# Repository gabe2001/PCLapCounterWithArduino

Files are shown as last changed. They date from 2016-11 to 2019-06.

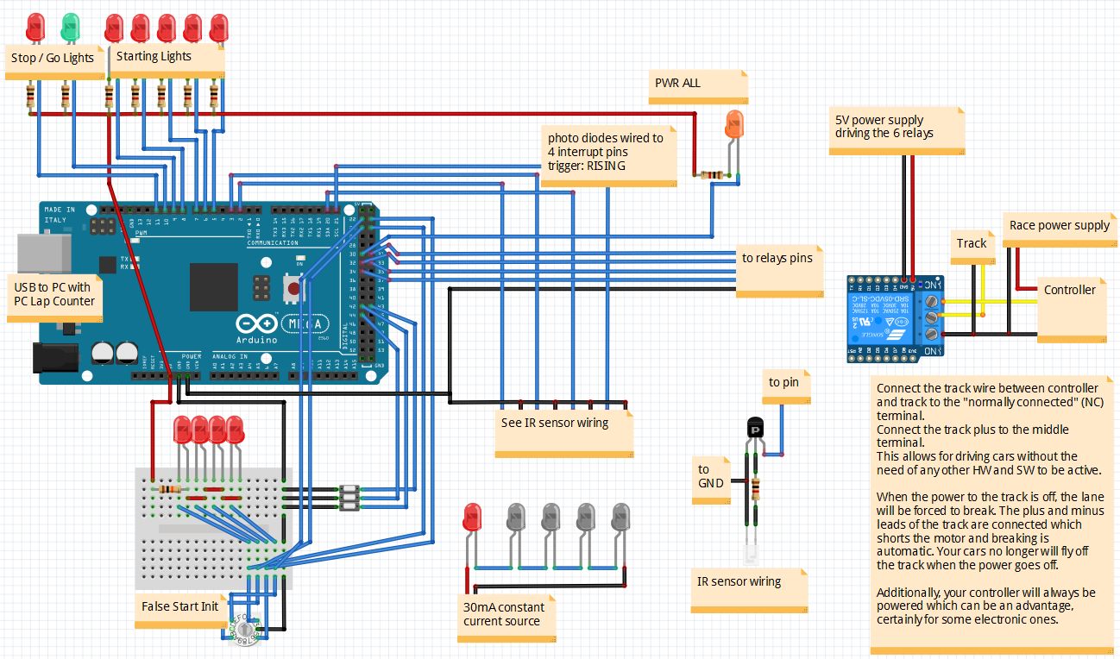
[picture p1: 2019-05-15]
resources/schema/PCLapCounterHWFourLanes.jpg

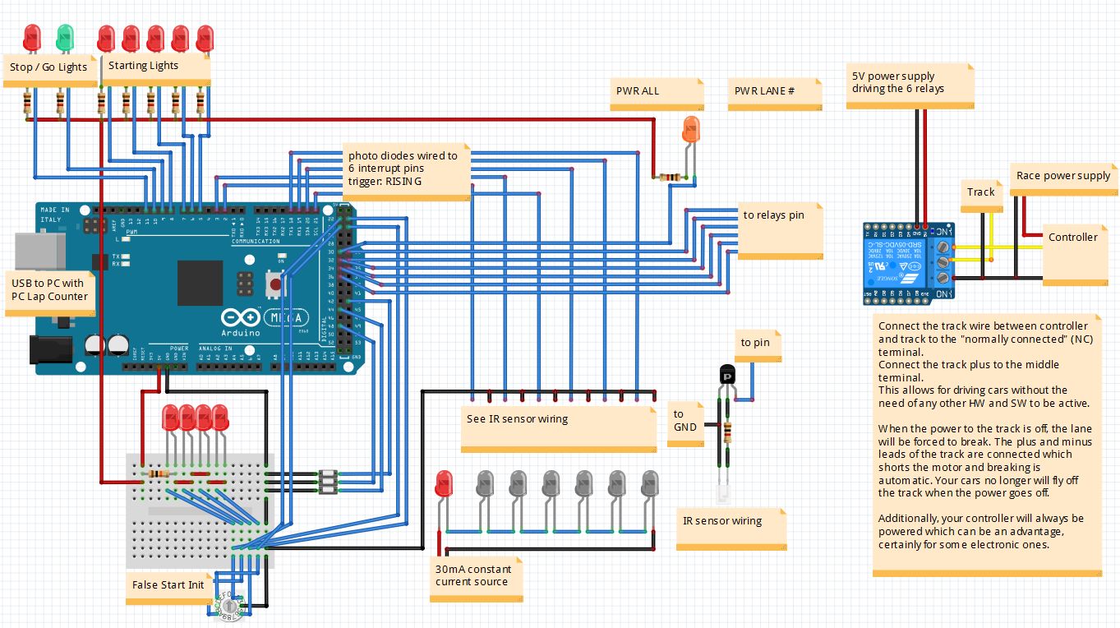
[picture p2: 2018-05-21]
resources/schema/PCLapCounterHW.jpg

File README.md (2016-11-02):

# PCLapCounterWithArduino
Arduino based modules for use with PC Lap Counter (www.pclapcounter.com)

<br />This work is licensed under a <a rel="license" href="http://creativecommons.org/licenses/by/4.0/">Creative Commons Attribution 4.0 International License</a>.

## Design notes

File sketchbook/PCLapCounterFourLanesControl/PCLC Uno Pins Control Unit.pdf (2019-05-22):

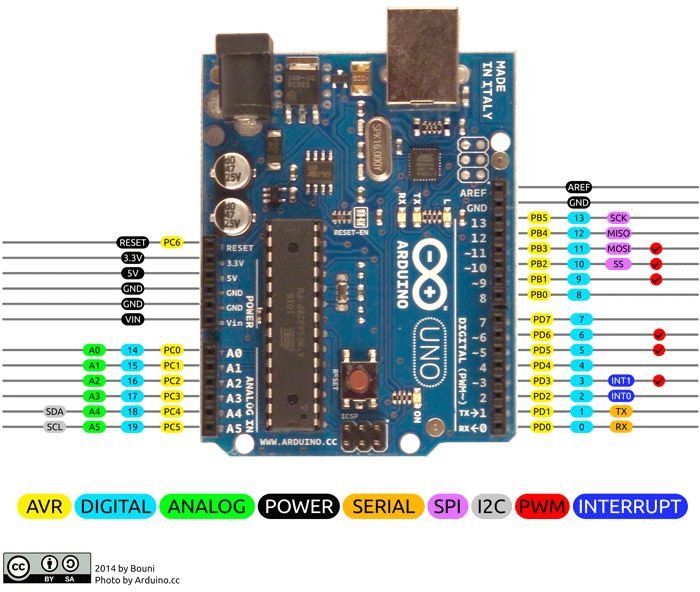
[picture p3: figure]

Pin | Function | Pin | Function
2 | LED_1 | A0
3 | LED_2 | A1
4 | LED_3 | A2 | PWR_ALL
5 | LED_4 | A3 | RACE_START
6 | LED_5 | A4 | RACE_RESTART
| | A5 | RACE_PAUSE
7 | LED_GO
8 | LED_CAUTION
9 | LED_STOP
10 | Lane 1 relay
11 | Lane 2 relay
12 | Lane 3 relay
13 | Lane 4 relay

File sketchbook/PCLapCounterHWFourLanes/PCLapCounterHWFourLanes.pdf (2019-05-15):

# el.Dude

/***************************************************************************************** Slotcar Race Controller for PCLapCounter Software

(C) Copyright 2016−2018 el.Dude − www.eldude.nl
5
Arduino MEGA 2560 based slotcar race controller. Capture start/finish signals, controls the power relays as well as any signal LEDs and manages external buttons.

See http://pclapcounter.be/arduino.html for the input/output protocol.
10 Minimum PC Lap Counter version: 5.40

Author: Gabriel Inäbnit
Date : 2016−10−14

15 TODO:
− Multi heat race proper false start and heat end detection
− disable track call button when race is not active (or change button behaviour)
− aborting start/restart is bogus

20 Revision History
__________ ____________________ _______________________________________________________
| 2017−05−20 Gabrile Inäbnit | Slimming down functionality and reduce to four lanes
| 2017−01−25 Gabriel Inäbnit | Light show pattern functionality
| 2017−01−22 Gabriel Inäbnit | LEDs and Relay code refactored with classes
25 | 2017−01−21 Gabriel Inäbnit | Lane detection blackout period added
| 2017−01−17 Gabriel Inäbnit | Interrupt to Lane mapping also configured with array
| 2017−01−16 Gabriel Inäbnit | Relays NC, r/g/y racer’s stand lights, lane mappings
| 2016−10−31 Gabriel Inäbnit | Race Clock − Race Finished status (RC2) PCLC v5.40
| 2016−10−28 Gabriel Inäbnit | Start/Finish lights on/off/blink depending race status
30 | 2016−10−25 Gabriel Inäbnit | Removed false start init button − no longer needed
| 2016−10−24 Gabriel Inäbnit | Fix false start GO command with HW false start enabled
| 2016−10−22 Gabriel Inäbnit | HW false start enable/disable, penalty, reset
| 2016−10−21 Gabriel Inäbnit | false start detection and penalty procedure
| 2016−10−18 Gabriel Inäbnit | external buttons handling added
35 | 2016−10−14 Gabriel Inäbnit | initial version
*****************************************************************************************/

/*****************************************************************************************
| Do not use pins:
40 | Serial1: 18 & 19 − used for interrupts
| Serial2: 16 & 17
| Serial3: 14 & 15
| BuiltIn: 13 − try to avoid it
*****************************************************************************************/
45
/*****************************************************************************************
| Global variables
*****************************************************************************************/ const long serialSpeed = 19200; // 19200;
50 const unsigned long laneProtectionTime = 3000L; // 3 seconds protection time
const byte laneToInterrupMapping[] = { 2, 3, 20, 21 };
| const byte laneToRelayMapping[] | = { 31, 32, 33, 34 };
| const char lapTime[][7] =
{
55 | "[SF01$",
| "[SF02$",
| "[SF03$",
| "[SF04$"
};
60
| const unsigned long delayMillis[] =
| { // index
| 0L, // 0
| 1000L, // 1
65 | 2000L, // 2
| 3000L, // 3
| 4000L, // 4
| 5000L, // 5
| 6000L, // 6
70 | 7000L // 7
};

/*****************************************************************************************
| Arduono Button Press Messages
75 | *****************************************************************************************/
| #define BUTTON_RACE_START | "[BT01]"
| #define BUTTON_RACE_RESTART | "[BT02]"
| #define BUTTON_RACE_PAUSE | "[BT03]"
May 22, 18 20:05 | PCLapCounterHW | Page 1/10
Tuesday May 22, 2018 | 1/10

# el.Dude

#define BUTTON_RACE_NEXT | "[BT04]"

80 | #define BUTTON_POWER_OFF | "[BT05]"
#define BUTTON_POWER_ON | "[BT06]"

#define BUTTON_END_OF_RACE | "[BT07]"

#define BUTTON_TOGGLE_POWER | "[BT08]"

#define BUTTON_TOGGLE_YELLOW_FLAG "[BT09]" 85 #define BUTTON_STOP_AND_GO_LANE1 "[SG01]" #define BUTTON_STOP_AND_GO_LANE2 "[SG02]"

#define BUTTON_STOP_AND_GO_LANE3 "[SG03]"

#define BUTTON_STOP_AND_GO_LANE4 "[SG04]"

90 /***************************************************************************************** Pin Naming
*****************************************************************************************/ // lane to interrup pin mapping
#define LANE_1 laneToInterrupMapping[0]

95 #define LANE_2 laneToInterrupMapping[1]
#define LANE_3 laneToInterrupMapping[2] #define LANE_4 laneToInterrupMapping[3]

#define LED_1 26

100 #define LED_2 25
#define LED_3 24

#define LED_4 23

#define LED_5 22

105 #define LED_GO 27
#define LED_CAUTION 28

#define LED_STOP 29

// PWR_x: x = lane
110 #define PWR_ALL 30

// False Start bits
#define FSbit_0 10

#define FSbit_1 8

115 #define FSbit_2 6
#define FSbit_3 4

// Buttons
#define RACE_START 41

120 #define RACE_RESTART 42
#define RACE_PAUSE 43

//#define POWER_TOGGLE 46
//#define RACE_START_PAUSE_RESTART 42

125 /***************************************************************************************** PC Lap Counter Messages
*****************************************************************************************/ #define SL_1_ON "SL011"
#define SL_1_OFF "SL010"

130 #define SL_2_ON "SL021"
#define SL_2_OFF "SL020"

#define SL_3_ON "SL031"

#define SL_3_OFF "SL030"

#define SL_4_ON "SL041"

135 #define SL_4_OFF "SL040"
#define SL_5_ON "SL051"

#define SL_5_OFF "SL050"

#define GO_ON | "SL061"

140 | #define GO_OFF | "SL060"
#define STOP_ON | "SL071"

#define STOP_OFF | "SL070"

#define CAUTION_ON "SL081" #define CAUTION_OFF "SL080"

145
#define PWR_ON | "PW001"

#define PWR_OFF | "PW000"

#define PWR_1_ON "PW011"

#define PWR_1_OFF "PW010"

150 #define PWR_2_ON "PW021"
#define PWR_2_OFF "PW020"

#define PWR_3_ON "PW031"

#define PWR_3_OFF "PW030"

#define PWR_4_ON "PW041"

155 | #define PWR_4_OFF "PW040"
2/10 | Tuesday May 22, 2018

# el.Dude

Class Race
*****************************************************************************************/
160 | #define RACE_INIT ’0’
| #define RACE_STARTED ’1’
| #define RACE_FINISHED ’2’
| #define RACE_PAUSED ’3’
| #define CLOCK_REMAINING_TIME ’R’
165 | #define CLOCK_ELAPSED_TIME ’E’
| #define CLOCK_SEGMENT_REMAINING_TIME ’S’
| #define LAPS_REMAINING ’L’
| class Race {
170 | protected:
| char state;
| char previousState;
| bool falseStartEnabled;
| bool falseStartDetected;
175 | bool startingLights;
| unsigned long penaltyBeginMillis;
| unsigned long penaltyServedMillis;
| unsigned long penaltyTimeMillis;
| void penaltyStart() {
180 | if (previousState ≡ RACE_INIT) {
| penaltyBeginMillis = millis(); // starting the race
| } else if (previousState ≡ RACE_PAUSED) { // resuming current race
| penaltyBeginMillis = penaltyBeginMillis
| + (millis() − penaltyBeginMillis)
185 | − penaltyServedMillis;
| }
| }
| unsigned long getPenaltyServedMillis() {
| if (falseStartDetected ∧ isStarted()) {
190 | penaltyServedMillis = millis() − penaltyBeginMillis;
| }
| return penaltyServedMillis;
| }
| public:
195 | Race() {
| state = RACE_FINISHED;
| previousState = RACE_FINISHED;
| falseStartEnabled = false;
| falseStartDetected = false;
200 | startingLights = LOW;
| penaltyBeginMillis = 0L;
| penaltyServedMillis = 0L;
| penaltyTimeMillis = 0L;
| }
205 | void initFalseStart(byte mode) {
| falseStartEnabled = mode > 7;
| if (falseStartEnabled) { // false start HW enabled
| falseStartDetected = false; // reset false start race "fuse"
| penaltyBeginMillis = 0xFFFFFFFF;
210 | penaltyServedMillis = 0;
| penaltyTimeMillis = delayMillis[mode − 8];
| }
| }
| void setFalseStartDetected() {
215 | falseStartDetected = true;
| }
| bool isFalseStartPenaltyServed() {
| return getPenaltyServedMillis() > penaltyTimeMillis;
| }
220 | bool isFalseStartDetected() {
| return falseStartDetected;
| }
| bool isFalseStartEnabled() {
| return falseStartEnabled;
225 | }
| bool isStarted() {
| return state ≡ RACE_STARTED;
| }
| bool isPaused() {
230 | return state ≡ RACE_PAUSED;
| }
| bool isFinished () {
| return state ≡ RACE_FINISHED;
| }

# el.Dude

235 | bool isInit() {
| return state ≡ RACE_INIT;
| }
| bool fromState(char from) {
| return from ≡ previousState;
240 | }
| void init() {
| previousState = state;
| state = RACE_INIT;
| }
245 | void start() {
| previousState = state;
| state = RACE_STARTED;
| penaltyStart();
| }
250 | void pause() {
| previousState = state;
| state = RACE_PAUSED;
| }
| void finish() {
255 | previousState = state;
| state = RACE_FINISHED;
| }
| void startingLightsOn() {
| startingLights = HIGH;
260 | }
| void startingLightsOff() {
| startingLights = LOW;
| }
| bool areStartingLightsOff() {
265 | return startingLights ≡ LOW;
| }
| bool areStartingLightsOn() {
| return startingLights ≡ HIGH;
| }
270 | };
| /*****************************************************************************************
| Class Race instantiations
| *****************************************************************************************/
275 | Race race;
| /*****************************************************************************************
| Class Lane
| *****************************************************************************************/
280 | class Lane {
| protected:
| volatile unsigned long start;
| volatile unsigned long finish;
| volatile unsigned long now;
285 | volatile long count;
| volatile bool reported;
| byte lane;
| byte pin;
| bool falseStart;
290 | public:
| Lane(byte setLane) {
| start = 0L;
| finish = 0L;
| count = −1L;
295 | lane = setLane − 1;
| pin = laneToRelayMapping[lane];
| reported = true;
| falseStart = false;
| }
300 | void lapDetected() { // called by ISR, short and sweet
| now = millis();
| if ((now − finish) < laneProtectionTime) {
| return;
| }
305 | start = finish;
| finish = now;
| count++;
| reported = false;
| }
310 | void reset() {
| reported = true;
| falseStart = false;

# el.Dude

count = −1L;

315 | void reportLap() { if (¬reported) {
| Serial.print(lapTime[lane]);
| Serial.print(finish − start);
| Serial.println(’]’);
320 | reported = true;
| }
| if (race.isFalseStartEnabled()) { if (race.isInit() ∧ ¬falseStart ∧ (count ≡ 0)) {
| // false start detected,
325 | // switching lane off immediately
| powerOff();
| falseStart = true;
| race.setFalseStartDetected(); // burn the race fuse
| }
330 | // switch power back on after false start penalty served if (falseStart ∧ race.isFalseStartPenaltyServed()) {
| falseStart = false; // reset false start lane "fuse"
| powerOn();
| }
335 | }
| }
| void powerOn() { if (¬falseStart) {
| digitalWrite(pin, HIGH);
340 | }
| }
| void powerOff() {
| digitalWrite(pin, LOW);
| }
345 | bool isFalseStart() {
| return falseStart;
| }
| };
350 | /*****************************************************************************************
| Class Lane instantiations
| *****************************************************************************************/
| Lane lane1(1);
| Lane lane2(2);
355 | Lane lane3(3);
| Lane lane4(4);
| /*****************************************************************************************
| Class Button − external buttons for PC Lap Counter
360 | *****************************************************************************************/
| class Button {
| protected:
| String button;
| byte pin;
365 | unsigned int sleep;
| bool reported;
| bool pressed;
| void reportButton() {
| Serial.println(button);
370 | reported = true;
| }
| public:
| Button(String setButton, byte setPin, unsigned int setSleep) {
| button = setButton;
375 | pin = setPin;
| sleep = setSleep;
| reported = false;
| pressed = false;
| pinMode(pin, INPUT_PULLUP);
380 | }
| void isButtonPressed() { pressed = ¬digitalRead(pin);
| if (¬reported ∧ pressed) {
| reportButton();
385 | delay(sleep);
| }
| reported = pressed;
| };
390

# el.Dude

Class Button instantiations *****************************************************************************************/
Button raceStart(BUTTON_RACE_START, | RACE_START, | 10);
395 | Button raceRestart(BUTTON_RACE_RESTART, RACE_RESTART, 10);
Button racePause(BUTTON_RACE_PAUSE, | RACE_PAUSE, | 10);

/***************************************************************************************** Class FalseStart − HW solution setup false start enable/disable, detection and penalty 400 *****************************************************************************************/ class FalseStart {
protected:
void reset() {
// reset false start flags
405 | lane1.reset();
lane2.reset();
lane3.reset();
lane4.reset();
}
410 public:
FalseStart() {
// empty constructor
}
void init() {
415 | // read pins of 4−bit encoder
byte mode = ¬digitalRead(FSbit_3) << 3 | ¬digitalRead(FSbit_2) << 2 |
¬digitalRead(FSbit_1) << 1 | ¬digitalRead(FSbit_0);
420 | race.initFalseStart(mode);
reset();
}
};

425 /***************************************************************************************** Class FalseStart instantiations *****************************************************************************************/ FalseStart falseStart;

430 /***************************************************************************************** initializations and configurations of I/O pins *****************************************************************************************/ void setup() {
// initialize serial communication
435 Serial.begin(serialSpeed);
while (¬Serial) {
; // wait for serial port to connect. Needed for native USB }
// interrup pins
440 pinMode(LANE_1, INPUT_PULLUP);
pinMode(LANE_2, INPUT_PULLUP); pinMode(LANE_3, INPUT_PULLUP); pinMode(LANE_4, INPUT_PULLUP); // input pins
445 pinMode(FSbit_0, INPUT_PULLUP); pinMode(FSbit_1, INPUT_PULLUP); pinMode(FSbit_2, INPUT_PULLUP); pinMode(FSbit_3, INPUT_PULLUP); // shake the dust off the relays
450 jiggleRelays();
delay(333);
setPowerOn(); // switch all power relays on
}

455 /***************************************************************************************** relays initialization − shake the dust off the contacts *****************************************************************************************/
#define CLICK 20

460 void jiggleRelays() {
allRelaysOn();
delay(CLICK);
allRelaysOff();
delay(222);
465 allRelaysOn();
delay(CLICK);
allRelaysOff();
delay(111);

# el.Dude

allRelaysOn();
470 | delay(CLICK);
| allRelaysOff();
| delay(111);
| allRelaysOn();
| delay(CLICK);
475 | allRelaysOff();
| delay(222);
| allRelaysOn();
| delay(CLICK);
| allRelaysOff();
480 | delay(444);
| allRelaysOn();
| delay(CLICK);
| allRelaysOff();
| delay(222);
485 | allRelaysOn();
| delay(CLICK);
| allRelaysOff();
| }
490 | /*****************************************************************************************
| Class LED
| *****************************************************************************************/
| class LED {
| protected:
495 | byte pin;
| public:
| LED (byte setPin) {
| pin = setPin;
| pinMode(pin, OUTPUT);
500 | }
| void on() {
| digitalWrite(pin, LOW);
| }
| void off() {
505 | digitalWrite(pin, HIGH);
| }
| };
| LED startFinishLED1(LED_1);
510 | LED startFinishLED2(LED_2);
| LED startFinishLED3(LED_3);
| LED startFinishLED4(LED_4);
| LED startFinishLED5(LED_5);
| LED ledGO(LED_GO);
515 | LED ledSTOP(LED_STOP);
| LED ledCaution(LED_CAUTION);
| LED ledPowerAll(PWR_ALL);
520 | /*****************************************************************************************
| Class Relay
| *****************************************************************************************/
| class Relay {
| protected:
525 | byte pin;
| public:
| Relay(byte lane) {
| pin = laneToRelayMapping[lane − 1];
| pinMode(pin, OUTPUT);
530 | }
| void on() {
| digitalWrite(pin, HIGH);
| }
| void off() {
535 | digitalWrite(pin, LOW);
| }
| };
| Relay relay1(1);
540 | Relay relay2(2);
| Relay relay3(3);
| Relay relay4(4);
545 | engage/disengage relays
| *****************************************************************************************/

# el.Dude

void allRelaysOn() {
relay1.on();
relay2.on();
550 | relay3.on();
| relay4.on();
| }
| void allRelaysOff() {
555 | relay1.off();
| relay2.off();
| relay3.off();
| relay4.off();
| }
560
| void setPowerOn() {
| ledPowerAll.on();
| allRelaysOn();
| setLEDsPowerOn();
565 | }
| void setPowerOff() {
| ledPowerAll.off();
| allRelaysOff();
570 | setLEDsPowerOff();
| }
| /*****************************************************************************************
| corresponding LEDs pattern for engage/disengage relays
575 | *****************************************************************************************/
| void setLEDsPowerOn() {
| startFinishLED1.off();
| startFinishLED2.off();
| startFinishLED3.off();
580 | startFinishLED4.off();
| startFinishLED5.off();
| ledGO.on();
| ledSTOP.off();
| ledCaution.off();
585 | }
| void setLEDsPowerOff() {
| startFinishLED1.on();
| startFinishLED2.on();
590 | startFinishLED3.on();
| startFinishLED4.on();
| startFinishLED5.on();
| ledGO.off();
| ledSTOP.on();
595 | ledCaution.off();
| }
| /*****************************************************************************************
| enable interrupts
600 | *****************************************************************************************/
| void attachAllInterrupts() {
| attachInterrupt(digitalPinToInterrupt(LANE_1), lapDetected1, RISING);
| attachInterrupt(digitalPinToInterrupt(LANE_2), lapDetected2, RISING);
| attachInterrupt(digitalPinToInterrupt(LANE_3), lapDetected3, RISING);
605 | attachInterrupt(digitalPinToInterrupt(LANE_4), lapDetected4, RISING);
| }
| /*****************************************************************************************
| disable interrupts
610 | *****************************************************************************************/
| void detachAllInterrupts() {
| detachInterrupt(digitalPinToInterrupt(LANE_1));
| detachInterrupt(digitalPinToInterrupt(LANE_2));
| detachInterrupt(digitalPinToInterrupt(LANE_3));
615 | detachInterrupt(digitalPinToInterrupt(LANE_4));
| }
| /*****************************************************************************************
| Interrup Service Routines (ISR) definitions
620 | *****************************************************************************************/
| void lapDetected1() {
| lane1.lapDetected();
| void lapDetected2() {

# el.Dude

625 lane2.lapDetected();

void lapDetected3() {
lane3.lapDetected();
}
630 void lapDetected4() {
lane4.lapDetected();
}

/***************************************************************************************** 635 Main loop
*****************************************************************************************/ void loop() {
detachAllInterrupts();
while (Serial.available()) {
640 | Serial.readStringUntil(’[’);
{
String output = Serial.readStringUntil(’]’);
String raceClockState = output.substring(0, 3); // RC#
// String raceClockTime = output.substring(4, 8); // HH:MM:SS
645 | if (raceClockState ≡ "RC0") { // Race Clock − Race Setup
if (race.fromState(RACE_FINISHED)) {
setPowerOff();
ledSTOP.off();
ledCaution.on();
650 | }
race.init();
falseStart.init();
// } else if (raceClockState == "RC1" && !race.isStarted) { // Race Clock − Race Started
// | race.start(); // misses the first second
655 | } else if (raceClockState ≡ "RC2") { // Race Clock − Race Finished
ledCaution.off();
startFinishLED1.on();
startFinishLED2.on();
startFinishLED3.on();
660 | startFinishLED4.on();
startFinishLED5.on();
ledSTOP.on();
race.finish();
} else if (raceClockState ≡ "RC3" ∧ ¬race.isPaused()) { // Race Clock − Race Paused
665 | race.pause(); // track call immediate, segment end after detection delay
} else if (output ≡ SL_1_ON) {
race.startingLightsOn(); // set race starting light state with LED1 only startFinishLED1.on();
} else if (output ≡ SL_1_OFF) {
670 | race.startingLightsOff(); // set race starting light state with LED1 only
startFinishLED1.off();
} else if (output ≡ SL_2_ON) { startFinishLED2.on();
} else if (output ≡ SL_2_OFF) {
675 | startFinishLED2.off();
} else if (output ≡ SL_3_ON) { startFinishLED3.on();
} else if (output ≡ SL_3_OFF) { startFinishLED3.off();
680 | } else if (output ≡ SL_4_ON) {
startFinishLED4.on();
} else if (output ≡ SL_4_OFF) { startFinishLED4.off();
} else if (output ≡ SL_5_ON) {
685 | startFinishLED5.on();
} else if (output ≡ SL_5_OFF) { startFinishLED5.off();
} else if (output ≡ GO_ON) { // race start race.start();
690 | ledGO.on();
ledCaution.off();
ledSTOP.off();
} else if (output ≡ GO_OFF) { // track call, segment or heat end race.pause();
695 | ledGO.off();
} else if (output ≡ STOP_ON) {
if (race.isPaused()) {
ledCaution.on();
} else {
700 | ledSTOP.on();
if (race.isPaused() ∧ race.fromState(RACE_STARTED)) { // blink

# el.Dude

ledCaution.on();
startFinishLED1.off();
705 | startFinishLED2.on();
| startFinishLED3.off();
| startFinishLED4.on();
| startFinishLED5.off();
| }
710 | } else if (output ≡ STOP_OFF) {
| ledSTOP.off();
| // flickers when race is continued (track or segment)
| if (race.isPaused() ∧
| race.fromState(RACE_STARTED) ∧
715 | race.areStartingLightsOff()) { // blink
| ledCaution.off();
| startFinishLED1.on();
| startFinishLED2.off();
| startFinishLED3.on();
720 | startFinishLED4.off();
| startFinishLED5.on();
| }
| } else if (output ≡ PWR_ON) {
| ledPowerAll.on();
725 | if (race.isStarted()) {
| ledCaution.off();
| }
| if (race.isFinished()) {
| setPowerOn();
730 | }
| } else if (output ≡ PWR_OFF) {
| ledPowerAll.off();
| if (race.isFinished()) {
| setPowerOff();
735 | }
| if (race.isPaused()) {
| ledCaution.on();
| }
| } else if (output ≡ PWR_1_ON) {
740 | lane1.powerOn();
| } else if (output ≡ PWR_1_OFF) {
| lane1.powerOff();
| } else if (output ≡ PWR_2_ON) {
| lane2.powerOn();
745 | } else if (output ≡ PWR_2_OFF) {
| lane2.powerOff();
| } else if (output ≡ PWR_3_ON) {
| lane3.powerOn();
| } else if (output ≡ PWR_3_OFF) {
750 | lane3.powerOff();
| } else if (output ≡ PWR_4_ON) {
| lane4.powerOn();
| } else if (output ≡ PWR_4_OFF) {
| lane4.powerOff();
755 | }
| }
| }
| /** report lap if necessary */
| lane1.reportLap();
760 | lane2.reportLap();
| lane3.reportLap();
| lane4.reportLap();
| /** any buttons pressed */
| raceStart.isButtonPressed();
765 | raceRestart.isButtonPressed();
| racePause.isButtonPressed();
| delay(3);
| attachAllInterrupts();
}
770

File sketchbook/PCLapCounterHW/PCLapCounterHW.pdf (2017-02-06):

# el.Dude

/***************************************************************************************** Slotcar Race Controller for PCLapCounter Software

(C) Copyright 2016−2017 el.Dude − www.eldude.nl
5
Arduino MEGA 2560 based slotcar race controller. Capture start/finish signals, controls the power relays as well as any signal LEDs and manages external buttons.

See http://pclapcounter.be/arduino.html for the input/output protocol.
10 | Minimum PC Lap Counter version: 5.40

Author: Gabriel Inäbnit
Date | : 2016−10−14
15 | TODO:
− Multi heat race proper false start and heat end detection
− disable track call button when race is not active (or change button behaviour)
− aborting start/restart is bogus
20 | Revision History
__________ ____________________ _______________________________________________________
2017−01−25 Gabriel Inäbnit | Light show pattern functionality
2017−01−22 Gabriel Inäbnit | LEDs and Relay code refactored with classes
2017−01−21 Gabriel Inäbnit | Lane detection blackout period added
25 | 2017−01−17 Gabriel Inäbnit | Interrupt to Lane mapping also configured with array
2017−01−16 Gabriel Inäbnit | Relays NC, r/g/y racer’s stand lights, lane mappings
2016−10−31 Gabriel Inäbnit | Race Clock − Race Finished status (RC2) PCLC v5.40
2016−10−28 Gabriel Inäbnit | Start/Finish lights on/off/blink depending race status
2016−10−25 Gabriel Inäbnit | Removed false start init button − no longer needed
30 | 2016−10−24 Gabriel Inäbnit | Fix false start GO command with HW false start enabled
2016−10−22 Gabriel Inäbnit | HW false start enable/disable, penalty, reset
2016−10−21 Gabriel Inäbnit | false start detection and penalty procedure
2016−10−18 Gabriel Inäbnit | external buttons handling added
2016−10−14 Gabriel Inäbnit | initial version
35 | *****************************************************************************************/

/***************************************************************************************** Do not use pins:
Serial1: 18 & 19 − used for interrupts
40 | Serial2: 16 & 17
Serial3: 14 & 15
BuiltIn: 13 − try to avoid it *****************************************************************************************/

45 /***************************************************************************************** Global variables
*****************************************************************************************/ const long serialSpeed = 19200; // 19200;
const long serial3Speed = 115200; // bluetooth
50 | const unsigned long laneProtectionTime = 9000L;
const byte laneToInterrupMapping[] = { 18, 19, 20, 21, | 3, | 2 };
const byte laneToRelayMapping[] | = { 12, 28, 11, | 9, | 7, | 5 };
const byte laneToGreenMapping[] | = { 44, 46, 38, 34, 39, 35 };
const byte laneToRedMapping[] | = { 41, 42, 40, 36, 32, 37 };
55 | const char lapTime[][7] =
{
"[SF01$",
"[SF02$",
"[SF03$",
60 "[SF04$",
"[SF05$",
"[SF06$"
};

65 const unsigned long delayMillis[] = { // index
0L, // 0
1000L, // 1
2000L, // 2
70 3000L, // 3
4000L, // 4
5000L, // 5
6000L, // 6
7000L | // 7
75 | };

/*****************************************************************************************
Light Show
Feb 06, 17 19:22 | PCLapCounterHW | Page 1/15
Monday February 06, 2017 | 1/15

# el.Dude

80 | patter positions:
0 | 1 | 2 | 3 | 4 | 5 | 6 | 7 | 8 | 9 | 10 | 11 | 12
_____________ | __ | ___ | ___ | ___ | ___ | ___ | __ | __ | __ | __ | __ | __
Duration [ms], Go, SF5, SF4, SF3, SF2, SF1, R6, R5, R4, R3, R2, R1 (STOP & CAUTION n/c)
85 | values: 0 = off, 1 = on (red), 2 = green (only for R1..R6), 3 = yellow (only for R1..R6)
*****************************************************************************************/ #define PATTERN_COLUMNS 13
const byte initPattern[][PATTERN_COLUMNS] = {
{50, 1, 1, 1, 1, 1, 1, 3, 3, 3, 3, 3, 3},
90 {50, 0, 0, 0, 0, 0, 0, 2, 2, 2, 2, 2, 2}, {50, 1, 1, 1, 1, 1, 1, 1, 1, 1, 1, 1, 1}, {50, 0, 0, 0, 0, 0, 0, 2, 2, 2, 2, 2, 2}, {50, 1, 1, 1, 1, 1, 1, 3, 3, 3, 3, 3, 3}, {50, 0, 0, 0, 0, 0, 0, 2, 2, 2, 2, 2, 2}, 95 {50, 1, 1, 1, 1, 1, 1, 1, 1, 1, 1, 1, 1}, {50, 0, 0, 0, 0, 0, 0, 0, 0, 0, 0, 0, 0}, {50, 1, 1, 0, 0, 0, 0, 0, 0, 0, 0, 0, 0}, {50, 0, 1, 1, 0, 0, 0, 0, 0, 0, 0, 0, 0}, {50, 1, 1, 1, 1, 0, 0, 0, 0, 0, 0, 0, 0}, 100 {50, 0, 1, 1, 1, 1, 0, 0, 0, 0, 0, 0, 0}, {50, 1, 1, 1, 1, 1, 1, 0, 0, 0, 0, 0, 0}, {50, 0, 1, 1, 1, 1, 1, 1, 0, 0, 0, 0, 0}, {50, 1, 1, 1, 1, 1, 1, 1, 1, 0, 0, 0, 0}, {50, 0, 1, 1, 1, 1, 1, 1, 1, 1, 0, 0, 0}, 105 {50, 1, 1, 1, 1, 1, 1, 1, 1, 1, 1, 0, 0}, {50, 0, 1, 1, 1, 1, 1, 1, 1, 1, 1, 1, 0}, {50, 1, 1, 1, 1, 1, 1, 1, 1, 1, 1, 1, 1}, {50, 0, 0, 1, 1, 1, 1, 1, 1, 1, 1, 1, 1}, {50, 1, 0, 0, 1, 1, 1, 1, 1, 1, 1, 1, 1}, 110 {50, 0, 0, 0, 0, 1, 1, 1, 1, 1, 1, 1, 1}, {50, 1, 0, 0, 0, 0, 1, 1, 1, 1, 1, 1, 1}, {50, 0, 0, 0, 0, 0, 0, 1, 1, 1, 1, 1, 1}, {50, 1, 0, 0, 0, 0, 0, 0, 1, 1, 1, 1, 1}, {50, 0, 0, 0, 0, 0, 0, 0, 0, 1, 1, 1, 1}, 115 {50, 1, 0, 0, 0, 0, 0, 0, 0, 0, 1, 1, 1}, {50, 0, 0, 0, 0, 0, 0, 0, 0, 0, 0, 1, 1}, {50, 1, 0, 0, 0, 0, 0, 0, 0, 0, 0, 0, 1}, {50, 0, 0, 0, 0, 0, 0, 0, 0, 0, 0, 0, 0} };
120
const byte showPattern[][PATTERN_COLUMNS] = { {66, 0, 1, 0, 0, 0, 0, 1, 0, 0, 0, 0, 0}, {66, 0, 0, 1, 0, 0, 0, 1, 1, 0, 0, 0, 0}, {66, 0, 0, 0, 1, 0, 0, 0, 1, 1, 0, 0, 0}, 125 {66, 0, 0, 0, 0, 1, 0, 0, 0, 1, 1, 0, 0}, {66, 0, 0, 0, 0, 0, 1, 0, 0, 0, 1, 1, 0}, {66, 1, 0, 0, 0, 0, 0, 0, 0, 0, 0, 1, 1}, {66, 0, 0, 0, 0, 0, 1, 0, 0, 0, 0, 0, 1}, {66, 0, 0, 0, 0, 1, 0, 0, 0, 0, 0, 1, 1}, 130 {66, 0, 0, 0, 1, 0, 0, 0, 0, 0, 1, 1, 0}, {66, 0, 0, 1, 0, 0, 0, 0, 0, 1, 1, 0, 0}, {66, 0, 1, 0, 0, 0, 0, 0, 1, 1, 0, 0, 0}, {66, 1, 0, 0, 0, 0, 0, 1, 1, 0, 0, 0, 0}, {66, 0, 1, 0, 1, 0, 1, 1, 0, 0, 0, 0, 0}, 135 {66, 1, 0, 1, 0, 1, 0, 2, 0, 0, 0, 0, 0}, {66, 0, 1, 0, 1, 0, 1, 2, 2, 0, 0, 0, 0}, {66, 1, 0, 1, 0, 1, 0, 0, 2, 2, 0, 0, 0}, {66, 0, 1, 0, 1, 0, 1, 0, 0, 2, 2, 0, 0}, {66, 1, 0, 1, 0, 1, 0, 0, 0, 0, 2, 2, 0}, 140 {66, 0, 1, 0, 0, 0, 0, 0, 0, 0, 0, 2, 2}, {66, 0, 0, 1, 0, 0, 0, 0, 0, 0, 0, 0, 2}, {66, 0, 0, 0, 1, 0, 0, 0, 0, 0, 0, 2, 2}, {66, 0, 0, 0, 0, 1, 0, 0, 0, 0, 2, 2, 0}, {66, 0, 0, 0, 0, 0, 1, 0, 0, 2, 2, 0, 0}, 145 {66, 1, 0, 0, 0, 0, 0, 0, 2, 2, 0, 0, 0}, {66, 0, 0, 0, 0, 0, 1, 2, 2, 0, 0, 0, 0}, {66, 0, 0, 0, 0, 1, 0, 2, 0, 0, 0, 0, 0}, {66, 0, 0, 0, 1, 0, 0, 3, 0, 0, 0, 0, 0}, {66, 0, 0, 1, 0, 0, 0, 3, 3, 0, 0, 0, 0}, 150 {66, 0, 1, 0, 0, 0, 0, 0, 3, 3, 0, 0, 0}, {66, 1, 0, 0, 0, 0, 0, 0, 0, 3, 3, 0, 0}, {66, 0, 1, 0, 1, 0, 1, 0, 0, 0, 3, 3, 0}, {66, 1, 0, 1, 0, 1, 0, 0, 0, 0, 0, 3, 3}, {66, 0, 1, 0, 1, 0, 1, 0, 0, 0, 0, 0, 3}, 155 {66, 1, 0, 1, 0, 1, 0, 0, 0, 0, 0, 3, 3},
{66, 0, 1, 0, 1, 0, 1, 0, 0, 0, 3, 3, 0},
2/15 | Monday February 06, 2017

# el.Dude

{66, 1, 0, 1, 0, 1, 0, 0, 0, 3, 3, 0, 0}, {66, 0, 1, 0, 0, 0, 0, 0, 3, 3, 0, 0, 0}, {66, 0, 0, 1, 0, 0, 0, 3, 3, 0, 0, 0, 0}, 160 {66, 0, 0, 0, 1, 0, 0, 3, 0, 0, 0, 0, 0}, {66, 0, 0, 0, 0, 1, 0, 0, 0, 0, 0, 0, 0}, {66, 0, 0, 0, 0, 0, 1, 1, 0, 1, 0, 1, 0}, {66, 1, 0, 0, 0, 0, 0, 0, 1, 0, 1, 0, 1}, {66, 0, 0, 0, 0, 0, 1, 1, 0, 1, 0, 1, 0}, 165 {66, 0, 0, 0, 0, 1, 0, 0, 1, 0, 1, 0, 1}, {66, 0, 0, 0, 1, 0, 0, 1, 0, 1, 0, 1, 0}, {66, 0, 0, 1, 0, 0, 0, 0, 1, 0, 1, 0, 1}, {66, 0, 1, 0, 0, 0, 0, 1, 0, 1, 0, 1, 0}, {66, 1, 0, 0, 0, 0, 0, 0, 1, 0, 1, 0, 1}, 170 {66, 0, 1, 0, 1, 0, 1, 3, 0, 3, 0, 3, 0}, {66, 1, 0, 1, 0, 1, 0, 0, 3, 0, 3, 0, 3}, {66, 0, 1, 0, 1, 0, 1, 3, 0, 3, 0, 3, 0}, {66, 1, 0, 1, 0, 1, 0, 0, 2, 0, 2, 0, 2}, {66, 0, 1, 0, 1, 0, 1, 2, 0, 2, 0, 2, 0}, 175 {66, 1, 0, 1, 0, 1, 0, 0, 2, 0, 2, 0, 2}, {66, 0, 1, 0, 1, 0, 1, 2, 0, 2, 0, 2, 0}, {66, 1, 0, 1, 0, 1, 0, 0, 2, 0, 2, 0, 2}, {66, 0, 1, 0, 1, 0, 1, 1, 1, 1, 1, 1, 1}, {66, 1, 0, 1, 0, 1, 0, 1, 1, 1, 1, 1, 1}, 180 {66, 0, 1, 0, 1, 0, 1, 1, 1, 1, 1, 1, 1}, {66, 1, 0, 1, 0, 1, 0, 0, 0, 0, 0, 0, 0}, {66, 0, 1, 0, 1, 0, 1, 1, 1, 1, 1, 1, 1}, {66, 1, 0, 1, 0, 1, 0, 0, 0, 0, 0, 0, 0}, {66, 0, 1, 0, 1, 0, 1, 1, 1, 1, 1, 1, 1}, 185 {66, 1, 0, 1, 0, 1, 0, 0, 0, 0, 0, 0, 0}, {66, 0, 1, 0, 1, 0, 1, 1, 1, 1, 1, 1, 1}, {66, 1, 0, 1, 0, 1, 0, 0, 0, 0, 0, 0, 0}, {66, 0, 1, 0, 1, 0, 1, 1, 1, 1, 1, 1, 1},
{255, 0, 0, 0, 0, 0, 0, 0, 0, 0, 0, 0, 0}
190 };

/*****************************************************************************************
| Arduono Button Press Messages
*****************************************************************************************/
195 | #define BUTTON_RACE_START | "[BT01]"
| #define BUTTON_RACE_RESTART | "[BT02]"
| #define BUTTON_RACE_PAUSE | "[BT03]"
| #define BUTTON_RACE_NEXT | "[BT04]"
| #define BUTTON_POWER_OFF | "[BT05]"
200 | #define BUTTON_POWER_ON | "[BT06]"
| #define BUTTON_END_OF_RACE | "[BT07]"
| #define BUTTON_TOGGLE_POWER | "[BT08]"
#define BUTTON_TOGGLE_YELLOW_FLAG "[BT09]"

| #define BUTTON_STOP_AND_GO_LANE1 | "[SG01]"
205 | #define BUTTON_STOP_AND_GO_LANE2 | "[SG02]"
| #define BUTTON_STOP_AND_GO_LANE3 | "[SG03]"
| #define BUTTON_STOP_AND_GO_LANE4 | "[SG04]"
| #define BUTTON_STOP_AND_GO_LANE5 | "[SG05]"
| #define BUTTON_STOP_AND_GO_LANE6 | "[SG06]"
210
/*****************************************************************************************
| Pin Naming
*****************************************************************************************/
| // lane to interrup pin mapping
215 | #define LANE_1 laneToInterrupMapping[0]
#define LANE_2 laneToInterrupMapping[1]

#define LANE_3 laneToInterrupMapping[2] #define LANE_4 laneToInterrupMapping[3] #define LANE_5 laneToInterrupMapping[4]

220 | #define LANE_6 laneToInterrupMapping[5]
| #define LED_1 23
| #define LED_2 25
| #define LED_3 27
225 | #define LED_4 29
| #define LED_5 31
| #define LED_DSR1 41
| #define LED_DSG1 44
230 | #define LED_DSR2 42
| #define LED_DSG2 46
| #define LED_DSR3 40
| #define LED_DSG3 38
| #define LED_DSR4 36

# el.Dude

235 #define LED_DSG4 34
#define LED_DSR5 32

#define LED_DSG5 39

#define LED_DSR6 37

#define LED_DSG6 35

240
#define LED_STOP 22

#define LED_CAUTION 24

#define LED_GO 26

245 // PWR_x: x = lane
#define PWR_ALL 30

#define PWR_1 | laneToRelayMapping[0] // 12

#define PWR_2 | laneToRelayMapping[1] // 28

#define PWR_3 | laneToRelayMapping[2] // 11

250 | #define PWR_4 | laneToRelayMapping[3] // | 9
| #define PWR_5 | laneToRelayMapping[4] // | 7
| #define PWR_6 | laneToRelayMapping[5] // | 5

#define FSbit_0 10

255 #define FSbit_1 8
#define FSbit_2 6

#define FSbit_3 4

/*****************************************************************************************
260 | PC Lap Counter Messages
*****************************************************************************************/
| #define SL_1_ON | "SL011"
#define SL_1_OFF "SL010"

| #define SL_2_ON | "SL021"
265 | #define SL_2_OFF "SL020"
| #define SL_3_ON | "SL031"
#define SL_3_OFF "SL030"

| #define SL_4_ON | "SL041"
#define SL_4_OFF "SL040"

270 | #define SL_5_ON | "SL051"
#define SL_5_OFF "SL050"

| #define GO_ON | "SL061"
| #define GO_OFF | "SL060"
275 | #define STOP_ON | "SL071"
| #define STOP_OFF | "SL070"
#define CAUTION_ON | "SL081"

#define CAUTION_OFF "SL080"

280 | #define PWR_ON | "PW001"
| #define PWR_OFF | "PW000"
| #define PWR_1_ON | "PW011"
#define PWR_1_OFF "PW010"

| #define PWR_2_ON | "PW021"
285 | #define PWR_2_OFF "PW020"
| #define PWR_3_ON | "PW031"
#define PWR_3_OFF "PW030"

| #define PWR_4_ON | "PW041"
#define PWR_4_OFF "PW040"

290 | #define PWR_5_ON | "PW051"
#define PWR_5_OFF "PW050"

| #define PWR_6_ON | "PW061"
#define PWR_6_OFF "PW060"

295 | /*****************************************************************************************
| Class Race
*****************************************************************************************/ #define RACE_INIT ’0’
#define RACE_STARTED ’1’

300 #define RACE_FINISHED ’2’
#define RACE_PAUSED ’3’

#define CLOCK_REMAINING_TIME ’R’ #define CLOCK_ELAPSED_TIME ’E’

#define CLOCK_SEGMENT_REMAINING_TIME ’S’

305 | #define LAPS_REMAINING ’L’
| class Race {
| protected:
| char state;
310 | char previousState;
bool falseStartEnabled;
bool falseStartDetected;

# el.Dude

bool startingLights;
unsigned long penaltyBeginMillis;
315 | unsigned long penaltyServedMillis;
unsigned long penaltyTimeMillis;
void penaltyStart() {
if (previousState ≡ RACE_INIT) {
penaltyBeginMillis = millis(); // starting the race
320 | } else if (previousState ≡ RACE_PAUSED) { // resuming current race
penaltyBeginMillis = penaltyBeginMillis
+ (millis() − penaltyBeginMillis) − penaltyServedMillis;
}
325 | }
unsigned long getPenaltyServedMillis() {
if (falseStartDetected ∧ isStarted()) { penaltyServedMillis = millis() − penaltyBeginMillis; }
330 | return penaltyServedMillis;
}
public:
Race() {
state = RACE_FINISHED;
335 | previousState = RACE_FINISHED;
falseStartEnabled = false; falseStartDetected = false; startingLights = LOW;
penaltyBeginMillis = 0L;
340 | penaltyServedMillis = 0L;
penaltyTimeMillis = 0L;
}
void debug() {
| Serial3.print(" | Started ? "); Serial3.println(isStarted() ? "yes" : "no");
345 | Serial3.print(" | Paused ? "); Serial3.println(isPaused() ? "yes" : "no");
| Serial3.print(" | Finished ? "); Serial3.println(isFinished () ? "yes" : "no");
| Serial3.print(" | Init ? "); Serial3.println(isInit() ? "yes" : "no");
| Serial3.print(" | state = ");
| switch (state) {
350 | case RACE_INIT: {
Serial3.println("Race Init");
| break;
| }
case RACE_STARTED: {
355 | Serial3.println("Race Started");
| break;
| }
case RACE_FINISHED: {
Serial3.println("Race Finished");
360 | break;
| }
case RACE_PAUSED: {
Serial3.println("Race Paused");
| break;
365 | }
| default: {
Serial3.println("unknown");
| }
| }
370 | Serial3.print(" | Served ? "); Serial3.println(isFalseStartPenaltyServed() ? "yes" : "no");
Serial3.print(" falseStartEnabled = "); Serial3.println(falseStartEnabled ? "yes" : "no"); Serial3.print(" falseStartDetected = "); Serial3.println(falseStartDetected ? "yes" : "no"); Serial3.print(" penaltyBeginMillis = "); Serial3.println(penaltyBeginMillis); Serial3.print("penaltyServedMillis = "); Serial3.println(getPenaltyServedMillis());
375 | Serial3.print(" penaltyTimeMillis = "); Serial3.println(penaltyTimeMillis);
| Serial3.print(" | now = "); Serial3.println(millis());
}
void initFalseStart(byte mode) {
falseStartEnabled = mode > 7;
380 | if (falseStartEnabled) { // false start HW enabled
falseStartDetected = false; // reset false start race "fuse" penaltyBeginMillis = 0xFFFFFFFF;
penaltyServedMillis = 0;
penaltyTimeMillis = delayMillis[mode − 8];
385 | }
}
void setFalseStartDetected() { falseStartDetected = true; }
390 | bool isFalseStartPenaltyServed() {

# el.Dude

return getPenaltyServedMillis() > penaltyTimeMillis; }
bool isFalseStartDetected() {
return falseStartDetected;
395 | }
| bool isFalseStartEnabled() {
| return falseStartEnabled;
| }
| bool isStarted() {
400 | return state ≡ RACE_STARTED;
| }
| bool isPaused() {
| return state ≡ RACE_PAUSED;
| }
405 | bool isFinished () {
| return state ≡ RACE_FINISHED;
| }
| bool isInit() {
| return state ≡ RACE_INIT;
410 | }
| bool fromState(char from) {
| return from ≡ previousState;
| }
| void init() {
415 | previousState = state;
| state = RACE_INIT;
| }
| void start() {
| previousState = state;
420 | state = RACE_STARTED;
| penaltyStart();
| }
| void pause() {
| previousState = state;
425 | state = RACE_PAUSED;
| }
| void finish() {
| previousState = state;
| state = RACE_FINISHED;
430 | }
| void startingLightsOn() {
| startingLights = HIGH;
| }
| void startingLightsOff() {
435 | startingLights = LOW;
| }
| bool areStartingLightsOff() {
| return startingLights ≡ LOW;
| }
440 | bool areStartingLightsOn() {
| return startingLights ≡ HIGH;
| }
| };
445 | /*****************************************************************************************
| Class Race instantiations
| *****************************************************************************************/
| Race race;
450 | /*****************************************************************************************
| Class Lane
| *****************************************************************************************/
| class Lane {
| protected:
455 | volatile unsigned long start;
| volatile unsigned long finish;
| volatile unsigned long now;
| volatile long count;
| volatile bool reported;
460 | byte lane;
| byte pin;
| byte green;
| byte red;
| bool falseStart;
465 | public:
| Lane(byte setLane) {
| start = 0L;
| finish = 0L;

# el.Dude

count = −1L;
470 | lane = setLane − 1;
| pin = laneToRelayMapping[lane];
| green = laneToGreenMapping[lane];
| red = laneToRedMapping[lane];
| reported = true;
475 | falseStart = false;
| }
| void lapDetected() { // called by ISR, short and sweet
| now = millis();
| if ((now − finish) < laneProtectionTime) {
480 | return;
| }
| start = finish;
| finish = now;
| count++;
485 | reported = false;
| }
| void reset() {
| reported = true;
| falseStart = false;
490 | count = −1L;
| }
| void reportLap() {
| if (¬reported) {
| Serial.print(lapTime[lane]);
495 | Serial.print(finish − start);
| Serial.println(’]’);
| reported = true;
| }
| if (race.isFalseStartEnabled()) {
500 | if (race.isInit() ∧ ¬falseStart ∧ (count ≡ 0)) {
| // false start detected,
| // switching lane off immediately
| powerOff();
| falseStart = true;
505 | race.setFalseStartDetected(); // burn the race fuse
| }
| // switch power back on after false start penalty served
| if (falseStart ∧ race.isFalseStartPenaltyServed()) {
| falseStart = false; // reset false start lane "fuse"
510 | powerOn();
| }
| }
| }
| void powerOn() {
515 | if (¬falseStart) {
| digitalWrite(pin, HIGH);
| digitalWrite(red, LOW);
| digitalWrite(green, HIGH);
| } else {
520 | digitalWrite(red, HIGH);
| digitalWrite(green, LOW);
| }
| }
| void powerOff() {
525 | digitalWrite(pin, LOW);
| digitalWrite(red, HIGH);
| digitalWrite(green, LOW);
| }
| bool isFalseStart() {
530 | return falseStart;
| }
| };
| /*****************************************************************************************
535 | Class Lane instantiations
| *****************************************************************************************/
| Lane lane1(1);
| Lane lane2(2);
| Lane lane3(3);
540 | Lane lane4(4);
| Lane lane5(5);
| Lane lane6(6);
| /*****************************************************************************************
545 | Class Button − external buttons for PC Lap Counter
| *****************************************************************************************/

# el.Dude

class Button {
protected:
String button;
550 | byte pin;
| unsigned int sleep;
| bool reported;
| bool pressed;
| void reportButton() {
555 | Serial.println(button);
| reported = true;
| }
| public:
Button(String setButton, byte setPin, unsigned int setSleep) {
560 | button = setButton;
| pin = setPin;
| sleep = setSleep;
| reported = false;
| pressed = false;
565 | pinMode(pin, INPUT_PULLUP);
| }
| void isButtonPressed() { pressed = ¬digitalRead(pin);
| if (¬reported ∧ pressed) {
570 | reportButton();
| delay(sleep);
| }
| reported = pressed;
| }
575 | };

/*****************************************************************************************
| Class Button instantiations
*****************************************************************************************/
580 | Button raceStart(BUTTON_RACE_START, | 47, 10); // pin 5 (RJ11 1)
| Button raceRestart(BUTTON_RACE_RESTART, | 45, 10); // pin 6 (RJ11 2)
| Button racePause(BUTTON_RACE_PAUSE, | 43, 10); // pin 7 (RJ11 3, RJ11 4 = GND)
Button raceStartPauseRestart(BUTTON_RACE_NEXT, 33, 100); // pin 1 (RJ11 n/c)
| //Button powerOff(BUTTON_POWER_OFF, 48);
585 | //Button powerOn(BUTTON_POWER_ON, 49);
| //Button endOfRace(BUTTON_END_OF_RACE, 50);
| //Button togglePower(BUTTON_TOGGLE_POWER, 51);
//Button toggleYelloFlag(BUTTON_TOGGLE_YELLOW_FLAG, 52); //Button stopAndGoLane1(BUTTON_STOP_AND_GO_LANE1);
590 //Button stopAndGoLane2(BUTTON_STOP_AND_GO_LANE2, 23); //Button stopAndGoLane3(BUTTON_STOP_AND_GO_LANE3", 24); //Button stopAndGoLane4(BUTTON_STOP_AND_GO_LANE4, 25); //Button stopAndGoLane5(BUTTON_STOP_AND_GO_LANE5, 26);
//Button stopAndGoLane6(BUTTON_STOP_AND_GO_LANE6, 27);
595
/***************************************************************************************** Class FalseStart − HW solution setup false start enable/disable, detection and penalty *****************************************************************************************/
| class FalseStart {
600 | protected:
| void reset() {
| // reset false start flags
| lane1.reset();
| lane2.reset();
605 | lane3.reset();
| lane4.reset();
| lane5.reset();
| lane6.reset();
| }
610 | public:
| FalseStart() {
| // empty constructor
| }
| void init() {
615 | // read pins of 4−bit encoder byte mode = ¬digitalRead(FSbit_3) << 3 |
| ¬digitalRead(FSbit_2) << 2 |
| ¬digitalRead(FSbit_1) << 1 |
| ¬digitalRead(FSbit_0);
620 | race.initFalseStart(mode);
| reset();
| }
| };

# el.Dude

625 | /*****************************************************************************************
| Class FalseStart instantiations
| *****************************************************************************************/
| FalseStart falseStart;
630 | /*****************************************************************************************
| initializations and configurations of I/O pins
| *****************************************************************************************/
| void setup() {
| // initialize serial communication
635 | Serial.begin(serialSpeed);
| while (¬Serial) {
| ; // wait for serial port to connect. Needed for native USB
| }
| Serial3.begin(serial3Speed);
640 | while (¬Serial3) {
| ; // wait...
| }
| // interrup pins
| pinMode(LANE_1, INPUT_PULLUP);
645 | pinMode(LANE_2, INPUT_PULLUP);
| pinMode(LANE_3, INPUT_PULLUP);
| pinMode(LANE_4, INPUT_PULLUP);
| pinMode(LANE_5, INPUT_PULLUP);
| pinMode(LANE_6, INPUT_PULLUP);
650 | // input pins
| pinMode(FSbit_0, INPUT_PULLUP);
| pinMode(FSbit_1, INPUT_PULLUP);
| pinMode(FSbit_2, INPUT_PULLUP);
| pinMode(FSbit_3, INPUT_PULLUP);
655 | // shake the dust off the relays
| jiggleRelays();
| delay(333);
| // light show
| lightShow(initPattern, sizeof(initPattern));
660 | delay(333);
| setPowerOn(); // switch all power relays on
| }
| /*****************************************************************************************
665 | relays initialization − shake the dust off the contacts
| *****************************************************************************************/
| #define CLICK 20
| void jiggleRelays() {
670 | allRelaysOn();
| delay(CLICK);
| allRelaysOff();
| delay(222);
| allRelaysOn();
675 | delay(CLICK);
| allRelaysOff();
| delay(111);
| allRelaysOn();
| delay(CLICK);
680 | allRelaysOff();
| delay(111);
| allRelaysOn();
| delay(CLICK);
| allRelaysOff();
685 | delay(222);
| allRelaysOn();
| delay(CLICK);
| allRelaysOff();
| delay(444);
690 | allRelaysOn();
| delay(CLICK);
| allRelaysOff();
| delay(222);
| allRelaysOn();
695 | delay(CLICK);
| allRelaysOff();
| }
| /*****************************************************************************************
700 | Class LED
| *****************************************************************************************/
| class LED {

# el.Dude

protected:
byte led;
705 | public:
| LED (byte setLed) {
| led = setLed;
| pinMode(led, OUTPUT);
| }
710 | void on() {
| digitalWrite(led, true);
| }
| void off() {
| digitalWrite(led, false);
715 | }
| };
| LED startFinishLED1(LED_1);
| LED startFinishLED2(LED_2);
720 | LED startFinishLED3(LED_3);
| LED startFinishLED4(LED_4);
| LED startFinishLED5(LED_5);
| LED ledGO(LED_GO);
| LED ledSTOP(LED_STOP);
725 | LED ledPowerAll(PWR_ALL);
| /*****************************************************************************************
| Class RacerStandLED
| *****************************************************************************************/
730 | class RacerStandLED {
| protected:
| byte greenPin;
| byte redPin;
| bool isRed;
735 | bool isGreen;
| void apply() {
| digitalWrite(greenPin, isGreen);
| digitalWrite(redPin, isRed);
| }
740 | public:
| RacerStandLED(byte lane) {
| greenPin = laneToGreenMapping[lane − 1];
| redPin = laneToRedMapping[lane − 1];
| pinMode(greenPin, OUTPUT);
745 | pinMode(redPin, OUTPUT);
| }
| void off() {
| isRed = false;
| isGreen = false;
750 | apply();
| }
| void red() {
| isRed = true;
| isGreen = false;
755 | apply();
| }
| void green() {
| isRed = false;
| isGreen = true;
760 | apply();
| }
| void yellow() {
| isRed = true;
| isGreen = true;
765 | apply();
| }
| };
| RacerStandLED racerStandLED1(1);
770 | RacerStandLED racerStandLED2(2);
| RacerStandLED racerStandLED3(3);
| RacerStandLED racerStandLED4(4);
| RacerStandLED racerStandLED5(5);
| RacerStandLED racerStandLED6(6);
775
| /*****************************************************************************************
| Class Relay
| *****************************************************************************************/
| class Relay {
780 | protected:

# el.Dude

byte pin;
public:
Relay(byte lane) {
pin = laneToRelayMapping[lane − 1];
785 | pinMode(pin, OUTPUT);
| }
| void on() {
| digitalWrite(pin, HIGH);
| }
790 | void off() {
| digitalWrite(pin, LOW);
| }
| };
795 | Relay relay1(1);
| Relay relay2(2);
| Relay relay3(3);
| Relay relay4(4);
| Relay relay5(5);
800 | Relay relay6(6);
| /*****************************************************************************************
| engage/disengage relays
| *****************************************************************************************/
805 | void allRelaysOn() {
| relay1.on();
| relay2.on();
| relay3.on();
| relay4.on();
810 | relay5.on();
| relay6.on();
| }
| void allRelaysOff() {
815 | relay1.off();
| relay2.off();
| relay3.off();
| relay4.off();
| relay5.off();
820 | relay6.off();
| }
| void setPowerOn() {
| ledPowerAll.on();
825 | allRelaysOn();
| setLEDsPowerOn();
| }
| void setPowerOff() {
830 | ledPowerAll.off();
| allRelaysOff();
| setLEDsPowerOff();
| }
835 | /*****************************************************************************************
| corresponding LEDs pattern for engage/disengage relays
| *****************************************************************************************/
| void setLEDsPowerOn() {
| startFinishLED1.off();
840 | startFinishLED2.off();
| startFinishLED3.off();
| startFinishLED4.off();
| startFinishLED5.off();
| ledGO.on();
845 | ledSTOP.off();
| setAllRacersGreen();
| }
| void setLEDsPowerOff() {
850 | startFinishLED1.on();
| startFinishLED2.on();
| startFinishLED3.on();
| startFinishLED4.on();
| startFinishLED5.on();
855 | ledGO.off();
| ledSTOP.on();
| setAllRacersRed();
| }

# el.Dude

860 void setAllRacersGreen() { racerStandLED1.green();
racerStandLED2.green();
racerStandLED3.green();
racerStandLED4.green();
865 racerStandLED5.green(); racerStandLED6.green();
}

void setAllRacersRed() {
870 racerStandLED1.red();
racerStandLED2.red();
racerStandLED3.red();
racerStandLED4.red();
racerStandLED5.red();
875 racerStandLED6.red();
}

void setAllRacersYellow() { racerStandLED1.yellow();
880 racerStandLED2.yellow(); racerStandLED3.yellow();
racerStandLED4.yellow();
racerStandLED5.yellow();
racerStandLED6.yellow();
885 }

void setAllRacersOff() {
racerStandLED1.off();
racerStandLED2.off();
890 racerStandLED3.off();
racerStandLED4.off();
racerStandLED5.off();
racerStandLED6.off();
}
895
/***************************************************************************************** Light Show
*****************************************************************************************/ void lightShow(const byte pattern[][PATTERN_COLUMNS], int totalSize) {
900 // noob note: we’re passing a pointer and the size is always sizeof(pattern) = 2!!!
int numberOfPatterns = totalSize / PATTERN_COLUMNS;
for (int i = 0; i < numberOfPatterns; i++) {
| pattern[i][1] | ≡ 1 ? ledGO.on() : ledGO.off();
| pattern[i][2] | ≡ 1 ? startFinishLED5.on() : startFinishLED5.off();
905 | pattern[i][3] | ≡ 1 ? startFinishLED4.on() : startFinishLED4.off();
| pattern[i][4] | ≡ 1 ? startFinishLED3.on() : startFinishLED3.off();
| pattern[i][5] | ≡ 1 ? startFinishLED2.on() : startFinishLED2.off();
| pattern[i][6] | ≡ 1 ? startFinishLED1.on() : startFinishLED1.off();
| pattern[i][7] | ≡ 1 ? racerStandLED6.red() :
910 | pattern[i][7] | ≡ 2 ? racerStandLED6.green() :
| pattern[i][7] | ≡ 3 ? racerStandLED6.yellow() : racerStandLED6.off();
| pattern[i][8] | ≡ 1 ? racerStandLED5.red() :
| pattern[i][8] | ≡ 2 ? racerStandLED5.green() :
| pattern[i][8] | ≡ 3 ? racerStandLED5.yellow() : racerStandLED5.off();
915 | pattern[i][9] | ≡ 1 ? racerStandLED4.red() :
| pattern[i][9] | ≡ 2 ? racerStandLED4.green() :
| pattern[i][9] | ≡ 3 ? racerStandLED4.yellow() : racerStandLED4.off();
pattern[i][10] ≡ 1 ? racerStandLED3.red() :
pattern[i][10] ≡ 2 ? racerStandLED3.green() :
920 | pattern[i][10] ≡ 3 ? racerStandLED3.yellow() : racerStandLED3.off();
pattern[i][11] ≡ 1 ? racerStandLED2.red() :
pattern[i][11] ≡ 2 ? racerStandLED2.green() :
pattern[i][11] ≡ 3 ? racerStandLED2.yellow() : racerStandLED2.off(); pattern[i][12] ≡ 1 ? racerStandLED1.red() :
925 | pattern[i][12] ≡ 2 ? racerStandLED1.green() :
pattern[i][12] ≡ 3 ? racerStandLED1.yellow() : racerStandLED1.off(); delay(pattern[i][0]);
}
}
930
/***************************************************************************************** enable interrupts
*****************************************************************************************/ void attachAllInterrupts() {
935 attachInterrupt(digitalPinToInterrupt(LANE_1), lapDetected1, RISING); attachInterrupt(digitalPinToInterrupt(LANE_2), lapDetected2, RISING);

# el.Dude

attachInterrupt(digitalPinToInterrupt(LANE_3), lapDetected3, RISING); attachInterrupt(digitalPinToInterrupt(LANE_4), lapDetected4, RISING); attachInterrupt(digitalPinToInterrupt(LANE_5), lapDetected5, RISING);
940 attachInterrupt(digitalPinToInterrupt(LANE_6), lapDetected6, RISING);
}

/***************************************************************************************** disable interrupts
945 *****************************************************************************************/ void detachAllInterrupts() {
detachInterrupt(digitalPinToInterrupt(LANE_1)); detachInterrupt(digitalPinToInterrupt(LANE_2)); detachInterrupt(digitalPinToInterrupt(LANE_3)); 950 detachInterrupt(digitalPinToInterrupt(LANE_4)); detachInterrupt(digitalPinToInterrupt(LANE_5)); detachInterrupt(digitalPinToInterrupt(LANE_6));
}

955 /***************************************************************************************** Interrup Service Routines (ISR) definitions *****************************************************************************************/ void lapDetected1() {
lane1.lapDetected();
960 }
void lapDetected2() {
lane2.lapDetected();
}
void lapDetected3() {
965 lane3.lapDetected();
}
void lapDetected4() {
lane4.lapDetected();
}
970 void lapDetected5() {
lane5.lapDetected();
}
void lapDetected6() {
lane6.lapDetected();
975 }

/***************************************************************************************** Main loop
*****************************************************************************************/ 980 void loop() {
detachAllInterrupts();
while (Serial3.available()) {
String command = Serial3.readStringUntil(’,’); if (command ≡ "show") {
985 | lightShow(showPattern, sizeof(showPattern));
setLEDsPowerOn();
}
if (command ≡ "init") {
lightShow(initPattern, sizeof(initPattern));
990 | setLEDsPowerOn();
}
if (command ≡ "status") {
race.debug();
}
995 | }
while (Serial.available()) { Serial.readStringUntil(’[’);
{
String output = Serial.readStringUntil(’]’);
1000 | Serial3.println(output);
String raceClockState = output.substring(0, 3); // RC#
// String raceClockTime = output.substring(4, 8); // HH:MM:SS if (raceClockState ≡ "RC0") { // Race Clock − Race Setup
if (race.fromState(RACE_FINISHED)) {
1005 | | setPowerOff();
| }
race.init();
falseStart.init();
// } else if (raceClockState == "RC1" && !race.isStarted) { // Race Clock − Race Started
1010 | // | race.start(); // misses the first second
} else if (raceClockState ≡ "RC2") { // Race Clock − Race Finished
race.finish();
startFinishLED1.on();
startFinishLED2.on();

# el.Dude

1015 | startFinishLED3.on();
| startFinishLED4.on();
| startFinishLED5.on();
| } else if (raceClockState ≡ "RC3" ∧ ¬race.isPaused()) { // Race Clock − Race Paused
| race.pause(); // track call immediate, segment end after detection delay
1020 | setAllRacersYellow();
| } else if (output ≡ SL_1_ON) {
| race.startingLightsOn(); // set race starting light state with LED1 only
| startFinishLED1.on();
| } else if (output ≡ SL_1_OFF) {
1025 | race.startingLightsOff(); // set race starting light state with LED1 only
| startFinishLED1.off();
| } else if (output ≡ SL_2_ON) {
| startFinishLED2.on();
| } else if (output ≡ SL_2_OFF) {
1030 | startFinishLED2.off();
| } else if (output ≡ SL_3_ON) {
| startFinishLED3.on();
| } else if (output ≡ SL_3_OFF) {
| startFinishLED3.off();
1035 | } else if (output ≡ SL_4_ON) {
| startFinishLED4.on();
| } else if (output ≡ SL_4_OFF) {
| startFinishLED4.off();
| } else if (output ≡ SL_5_ON) {
1040 | startFinishLED5.on();
| } else if (output ≡ SL_5_OFF) {
| startFinishLED5.off();
| } else if (output ≡ GO_ON) { // race start
| race.start();
1045 | ledGO.on();
| setAllRacersGreen();
| } else if (output ≡ GO_OFF) { // track call, segment or heat end
| race.pause();
| ledGO.off();
1050 | } else if (output ≡ STOP_ON) {
| ledSTOP.on();
| if (race.isPaused() ∧ race.fromState(RACE_STARTED)) { // blink
| startFinishLED1.off();
| startFinishLED2.on();
1055 | startFinishLED3.off();
| startFinishLED4.on();
| startFinishLED5.off();
| setAllRacersYellow();
| }
1060 | } else if (output ≡ STOP_OFF) {
| ledSTOP.off();
| // flickers when race is continued (track or segment)
| if (race.isPaused() ∧
| race.fromState(RACE_STARTED) ∧
1065 | race.areStartingLightsOff()) { // blink
| startFinishLED1.on();
| startFinishLED2.off();
| startFinishLED3.on();
| startFinishLED4.off();
1070 | startFinishLED5.on();
| setAllRacersOff();
| }
| } else if (output ≡ PWR_ON) {
| ledPowerAll.on();
1075 | setAllRacersYellow();
| if (race.isFinished()) {
| setPowerOn();
| }
| } else if (output ≡ PWR_OFF) {
1080 | ledPowerAll.off();
| if (race.isFinished()) {
| setPowerOff();
| }
| } else if (output ≡ PWR_1_ON) {
1085 | lane1.powerOn();
| } else if (output ≡ PWR_1_OFF) {
| lane1.powerOff();
| } else if (output ≡ PWR_2_ON) {
| lane2.powerOn();
1090 | } else if (output ≡ PWR_2_OFF) {
| lane2.powerOff();
| } else if (output ≡ PWR_3_ON) {

# el.Dude

lane3.powerOn();
} else if (output ≡ PWR_3_OFF) {
1095 | lane3.powerOff();
| } else if (output ≡ PWR_4_ON) {
| lane4.powerOn();
| } else if (output ≡ PWR_4_OFF) {
| lane4.powerOff();
1100 | } else if (output ≡ PWR_5_ON) {
| lane5.powerOn();
| } else if (output ≡ PWR_5_OFF) {
| lane5.powerOff();
| } else if (output ≡ PWR_6_ON) {
1105 | lane6.powerOn();
| } else if (output ≡ PWR_6_OFF) {
| lane6.powerOff();
| } else if (raceClockState ≡ "DEB") {
| race.debug();
1110 | }
| }
| }
| /** report lap if necessary */
| lane1.reportLap();
1115 | lane2.reportLap();
| lane3.reportLap();
| lane4.reportLap();
| lane5.reportLap();
| lane6.reportLap();
1120 | /** any buttons pressed */
| raceStart.isButtonPressed();
| raceRestart.isButtonPressed();
| racePause.isButtonPressed();
| delay(3);
1125 | attachAllInterrupts();
}

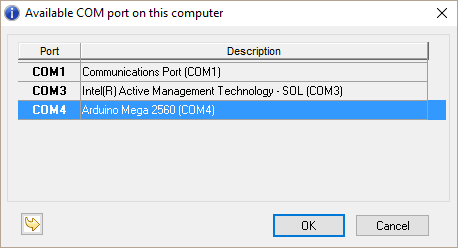
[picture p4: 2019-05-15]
resources/PCLapCounter/COM-Ports-Selection.png

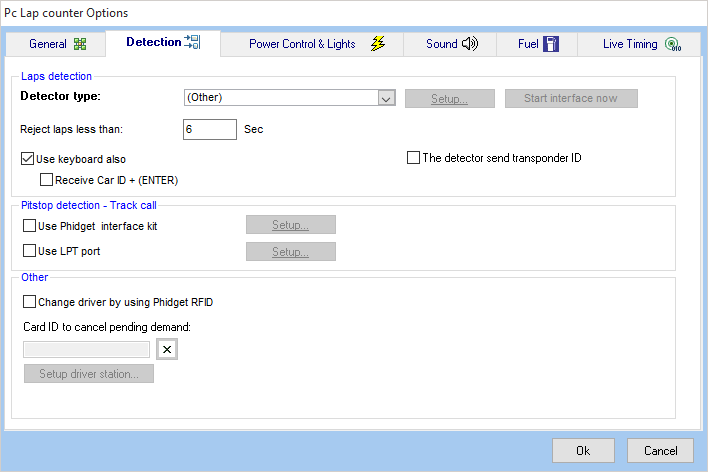
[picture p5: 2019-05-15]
resources/PCLapCounter/PCLC_Options_Detection.png

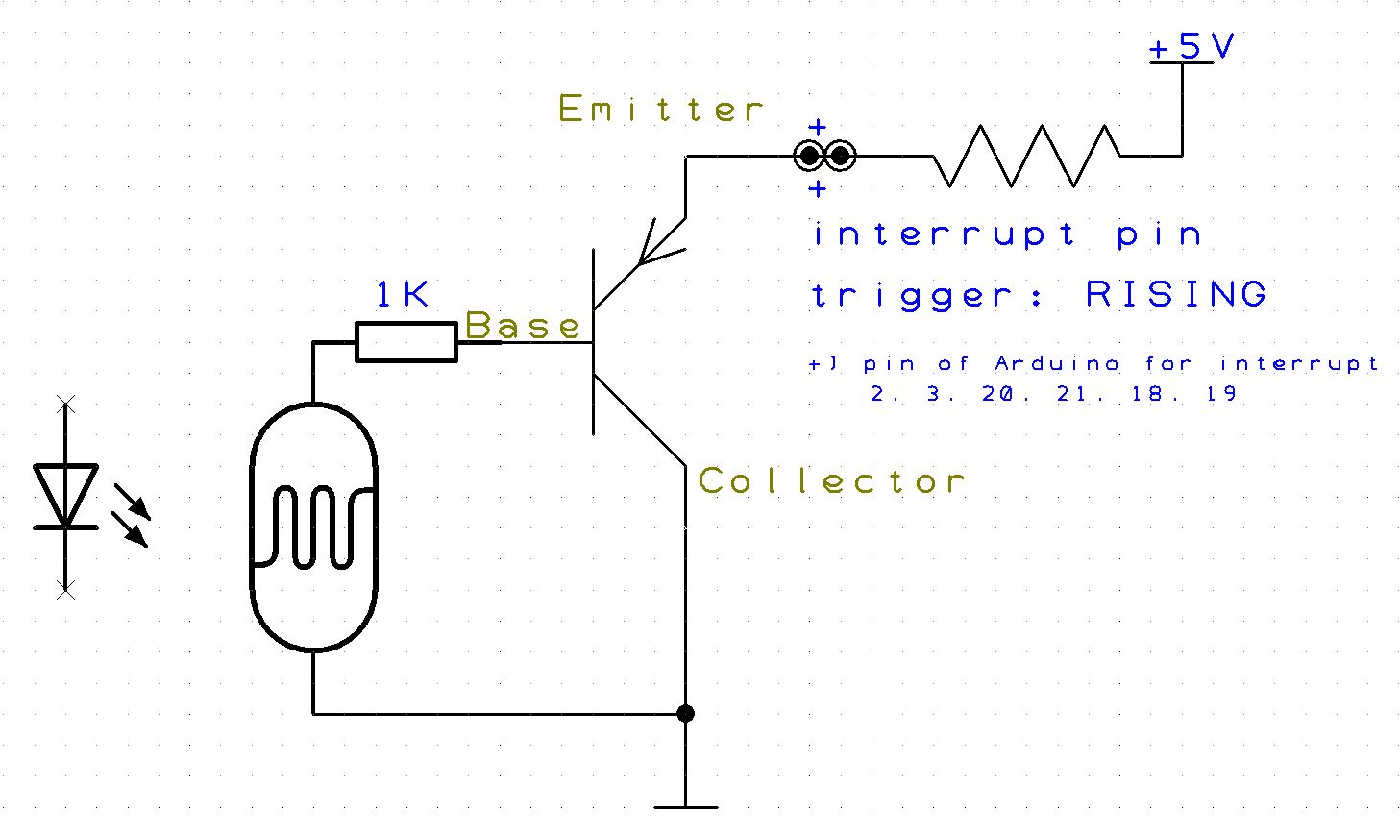
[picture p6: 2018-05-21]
resources/schema/PhotoDiodeSensor.jpg

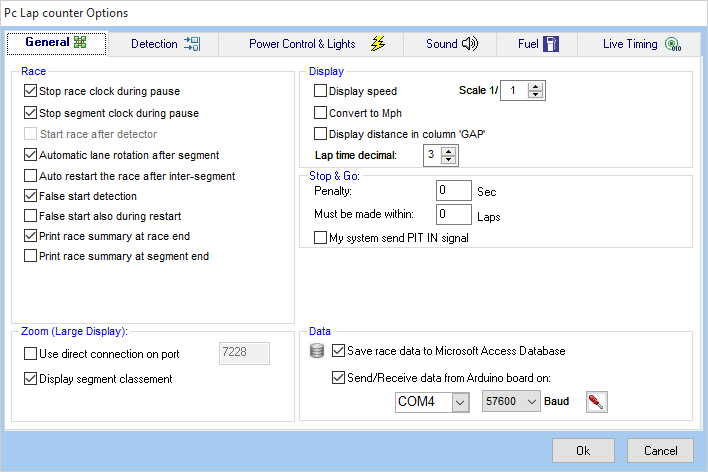
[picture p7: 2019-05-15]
resources/PCLapCounter/PCLC_Options_General.png

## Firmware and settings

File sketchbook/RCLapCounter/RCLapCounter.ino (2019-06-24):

/*
   Arduino slot car lap sensor

   I/O Sketch - V1.0.0.10

   The Race Coordinator Arduino sketch is covered by the Creative Commons - Attribution-NonCommercial-ShareAlike 4.0 International license.
   Copyright 2014 by Dave Aufderheide and Kevin Gee.  All rights reserved.
   If you find this sketch and corresponding wiring suggestions useful please
   consider making a donation to the RC charity
   http://racecoordinator.net/charity.html

   This is a human-readable summary of (and not a substitute for) the license which can be found here:
   http://creativecommons.org/licenses/by-nc-sa/4.0/legalcode

   You are free to:

   Share — copy and redistribute the material in any medium or format
   Adapt — remix, transform, and build upon the material
   The licensor cannot revoke these freedoms as long as you follow the license terms.
   Under the following terms:

   Attribution — You must give appropriate credit, provide a link to the license, and indicate if changes were made. You may do so in any reasonable manner, but not in any way that suggests the licensor endorses you or your use.
   NonCommercial — You may not use the material for commercial purposes.
   ShareAlike — If you remix, transform, or build upon the material, you must distribute your contributions under the same license as the original.
   No additional restrictions — You may not apply legal terms or technological measures that legally restrict others from doing anything the license permits.
   Notices:

   You do not have to comply with the license for elements of the material in the public domain or where your use is permitted by an applicable exception or limitation.
   No warranties are given. The license may not give you all of the permissions necessary for your intended use. For example, other rights such as publicity, privacy, or moral rights may limit how you use the material.

   For complete license details please visit:
   http://creativecommons.org/licenses/by-nc-sa/4.0/
*/
#define WITH_FAST_LED
#define WITH_WATCH_DOG
//#define WITH_SERIAL_DEBUG

#ifdef WITH_WATCH_DOG
#include <avr/wdt.h>
#endif

#ifdef WITH_FAST_LED
#include <FastLED.h>
#endif

const byte term             = 0x3B;  // ;

// Version is "major"."minor"."patch"."drop"
// V1.0.0.10
const byte rcVersion[]     = {0x56, 0x01, 0x00, 0x00, 0x0a, term};

// Setting for the baud rate RC will run at 115200
const long iBaudRate = 115200;

// Bytes for messages
const byte resetRequest     = 0x52;  // R
const byte pinModeRequest   = 0x50;  // P
const byte writeRequest     = 0x4F;  // O
const byte analogRequest    = 0x41;  // A
const byte digitalRequest   = 0x44;  // D
const byte extendedRequest  = 0x45;  // E
const byte getInfoRequest   = 0x47;  // G
const byte analogPollRate   = 0x61;  // a
const byte versionRequest   = 0x56;  // V
const byte timeResetRequest = 0x54;  // T
const byte debounceRequest  = 0x64;  // d
const byte ledModeRequest   = 0x6C;  // l
const byte ledWriteRequest  = 0x4C;  // L

byte timeResponse[]        = {0x54, 0x00, 0x00, 0x00, 0x00, 0, term};

byte inputChanged[] = {0x49, 0xFF, 0xFF, 0xFF, term};

// Unknown
const byte getInfo[] = {0x47, 0x3F, 0xFF, 0xFF, term};  // G ? -1 -1 ;
// Trinket
//const byte getInfo[] = {0x47, 0x54, 0x05, 0x00, term};  // G T 5 0 ;
// Nano
//const byte getInfo[] = {0x47, 0x4E, 0x08, 0x0E, term};  // N N 8 14 ;
// Uno
//const byte getInfo[] = {0x47, 0x55, 0x06, 0x0E, term};  // G U 6 14 ;
// Mega
//const byte getInfo[] = {0x47, 0x4D, 0x10, 0x36, term};  // G M 16 54 ;

int iPinSignal                        = HIGH;
int iNumReadPins                      = 0;
int* pReadPins                        = NULL;
int* pLastReadSignal                  = NULL;

unsigned long ulDebounceHighUs        = 0;
unsigned long ulDebounceLowUs         = 0;
int* pDebounceState                   = NULL;
int* pDebounceNextState               = NULL;
unsigned long* pDebounceTime          = NULL;

boolean bReset                        = true;
int iNumWritePins                     = 0;

// inBuffer will hold any requests made by RC i.e. power control
byte inBuffer[512];
int iReadCount                          = 0;
boolean bRead                           = false;

// Hw timing
unsigned long ulPrevHwTimeUs;

// Just keep track of last keepAlive signal
unsigned long ulPrevPingUs;
unsigned long ulPingTimeUs = 1000000UL;
#ifdef WITH_SERIAL_DEBUG
#define INT_TO_TXT_CONVERSION  + '0'
#define TXT_TO_INT_CONVERSION  - '0'

#define SERIAL_PRINT(x) Serial.print(x);
#define SERIAL_PRINTLN(x) Serial.println(x);
#else
#define INT_TO_TXT_CONVERSION
#define TXT_TO_INT_CONVERSION

#define SERIAL_PRINT(x)
#define SERIAL_PRINTLN(x)
#endif

unsigned long ulCurDebounceUs;
unsigned long ulAnalogMs;
unsigned long ulAnalogDeltaMs = 100UL;

#ifdef WITH_FAST_LED
// RGB pixels
#define MAX_RGB_LED_STRINGS 4
#define STRING_PIN_1  A0
#define STRING_PIN_2  A1
#define STRING_PIN_3  A2
#define STRING_PIN_4  A3

// Here's all the types of leds FastLed supports.  There are actually others that require a CLOCK pin
// that we could support but as of right now I didn't bother.
//  #define LED_TYPE_1 TM1803
//  #define LED_TYPE_1 TM1804
//  #define LED_TYPE_1 TM1809
//  #define LED_TYPE_1 WS2811
//  #define LED_TYPE_1 WS2812
//  #define LED_TYPE_1 WS2812B
//  #define LED_TYPE_1 APA104
//  #define LED_TYPE_1 UCS1903
//  #define LED_TYPE_1 UCS1903B
//  #define LED_TYPE_1 GW6205
//  #define LED_TYPE_1 GW6205_400

#define LED_TYPE_1 WS2811
#define LED_TYPE_2 WS2811
#define LED_TYPE_3 WS2811
#define LED_TYPE_4 WS2811

// Comment in LED_TYPE_1 through LED_TYPE_4 and set them to the correct value.  Then comment in
// these 4 macros, OR leave these 4 macros commented out and comment in the 4 NEOPIXEL macros
// which are basically WS2811 with the color format set to GRB.
//#define SETUP_LED_1(leds, numLeds) FastLED.addLeds<LED_TYPE_1, STRING_PIN_1, RGB>(leds, numLeds);
//#define SETUP_LED_2(leds, numLeds) FastLED.addLeds<LED_TYPE_2, STRING_PIN_2, RGB>(leds, numLeds);
//#define SETUP_LED_3(leds, numLeds) FastLED.addLeds<LED_TYPE_3, STRING_PIN_3, RGB>(leds, numLeds);
//#define SETUP_LED_4(leds, numLeds) FastLED.addLeds<LED_TYPE_4, STRING_PIN_4, RGB>(leds, numLeds);

#define SETUP_LED_1(leds, numLeds) FastLED.addLeds<NEOPIXEL, STRING_PIN_1>(leds, numLeds);
#define SETUP_LED_2(leds, numLeds) FastLED.addLeds<NEOPIXEL, STRING_PIN_2>(leds, numLeds);
#define SETUP_LED_3(leds, numLeds) FastLED.addLeds<NEOPIXEL, STRING_PIN_3>(leds, numLeds);
#define SETUP_LED_4(leds, numLeds) FastLED.addLeds<NEOPIXEL, STRING_PIN_4>(leds, numLeds);
      
typedef struct {
  int numLeds;
  CRGB* leds;
} s_rgbLedString;
s_rgbLedString rgbLedStrings[MAX_RGB_LED_STRINGS];
CLEDController *rgbLedControllers[MAX_RGB_LED_STRINGS];
byte rgbLedBrightness[MAX_RGB_LED_STRINGS];
int rgbLedUpdateRateMs = 20;
boolean rgbLedUpdateString[MAX_RGB_LED_STRINGS];
unsigned long rgbLedUpdateTime;
boolean rgbLedInit = false;
#endif
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

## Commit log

2016-10-24 HW False Start init button works now
    will be replaced with Race clock messages
    [PCLapCounterHW.ino]
2016-10-25 False Start init button removed
2016-10-26 it's not working anymore - to tired...
    [PCLapCounterHW.ino]
2016-10-26 false start penalty and track call handling
2016-10-26 pretty printing
2016-10-26 prettier print
2016-10-27 Notes and race power supply added
2016-10-31 fixed flickering start lights and using RC2... from PCLC 5.40
    [PCLapCounterHW.ino]
2016-10-31 race lights on/off depending on power status and not racing
2016-11-03 relays now NC when power is on
    TODO - use NPN transistors to drive the LEDs with the inverse logic
2017-01-12 rearranged pins, explicit mapping lanes/LEDs to pins
2017-01-14 avoiding use of pin 13
    [PCLapCounterHW.ino]
2017-01-16 logic updates to accommodate LED HW driver circuits
2017-01-21 button message defined
2017-02-06 patterns and corrected lightShow function
    [PCLapCounterHW.ino]
2018-05-21 schema updated
    [PCLapCounterHW.fzz]
2019-05-15 consolidated all PCLapCounter code in singel repo
    [PCLapCounterHW.fzz, PCLapCounterHWFourLanes.fzz]
2019-05-22 Update PCLapCounterFourLanesControl.ino
    analog ports "numbering" updated
    race start/restart/pause buttons enabled and race start-pause-restart combo button disabled
2019-05-22 using enabled buttons - PDF doc updated
2019-06-23 Create RCLapCounter.ino
    Arduino (UNO) Sketch from Race Coordinator installer (www.racecoordinator.net)
